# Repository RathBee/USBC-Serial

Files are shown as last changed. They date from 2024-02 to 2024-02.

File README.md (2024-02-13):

A compact USB-C to UART bridge with independent UART IO power rail utlizing the CH343 chip

Main features:

  1.UART interface I/O powered independently, never worry about backfeeding again.

  2.High baud rate. Maximum speed up to 6Mbps.

  3.Supports USB CDC driver. No annoying driver instalation anymore.

  4.Correctly implemented USB-C port, you can use any cable you like.
  (some badly designed USB-C device tends to lack the two 5.1k pull-down resistor, or shorts two cc pin together, causing the device to become unusable when using certain C to C cables)

  5.Compact. (2cm x 2.6cm)





Warning: Do not try to power you external circuit with this board's 3.3V pin, the CH343's internal regulator can only handle 10mA of current.
Instead, this pin should only be used to power the CH343's internal UART transciver. 

You can short the 5V pin to the VIO pin to get 5V level UART output. It's the same for 3.3V.

You can also power the CH343's UART transciver using your own power supply, for example, your MCU's power supply(assuming you are connecting this board to a MCU).
This way, you can have arbitary UART voltage level ranging from 1.7V to 5.5V. And you don't have to worry about backfeeding.

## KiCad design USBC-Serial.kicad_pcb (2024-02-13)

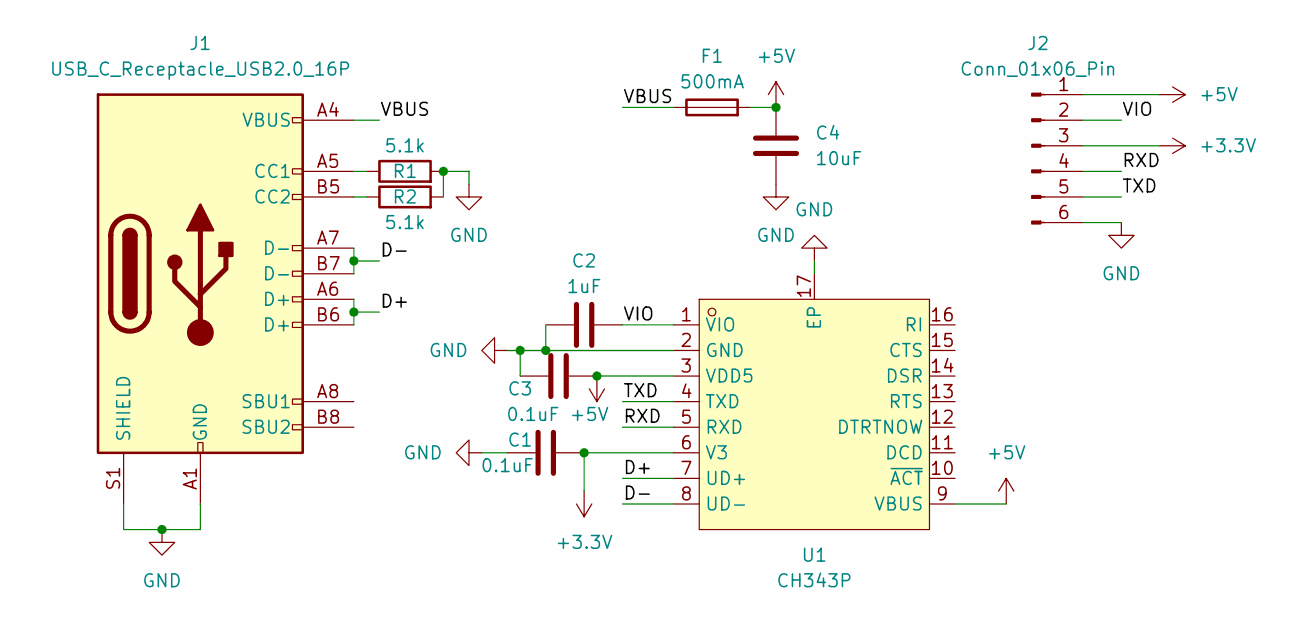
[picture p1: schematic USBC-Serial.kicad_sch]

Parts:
C1, C3: 0.1uF; C_0805_2012Metric
C2: 1uF; C_0805_2012Metric
C4: 10uF; C_0805_2012Metric
F1: 500mA; Fuse_1206_3216Metric
J1: USB_C_Receptacle_USB2.0_16P; USB_C_Receptacle_HRO_TYPE-C-31-M-12
J2: Conn_01x06_Pin; PinHeader_1x06_P2.54mm_Horizontal
R1, R2: 5.1k; R_0805_2012Metric
U1: CH343P; TQFN-16_L3.0-W3.0-P0.50-BL-EP1.7; LCSC Part C2846043

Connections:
+3.3V: C1.1, J2.3, U1.6 (V3)
+5V: C3.2, C4.1, F1.2, J2.1, U1.3 (VDD5), U1.9 (VBUS)
/D+: J1.A6 (D+), J1.B6 (D+), U1.7 (UD+)
/D-: J1.A7 (D-), J1.B7 (D-), U1.8 (UD-)
/RXD: J2.4, U1.5 (RXD)
/TXD: J2.5, U1.4 (TXD)
/VBUS: F1.1, J1.A4 (VBUS), J1.A9 (VBUS), J1.B4 (VBUS), J1.B9 (VBUS)
/VIO: C2.2, J2.2, U1.1 (VIO)
GND: C1.2, C2.1, C3.1, C4.2, J1.A1 (GND), J1.A12 (GND), J1.B1 (GND), J1.B12 (GND), J1.S1 (SHIELD), J2.6, R1.2, R2.2, U1.2 (GND), U1.17 (EP)
unnamed: J1.A5 (CC1), R1.1
unnamed: J1.B5 (CC2), R2.1

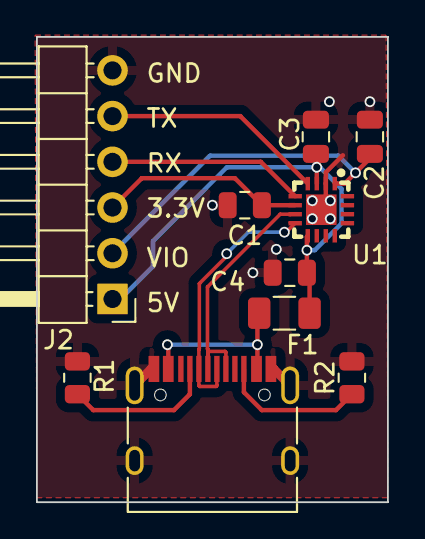
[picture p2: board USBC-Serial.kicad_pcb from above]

Board: 2 copper layers, 19.5 x 25.9 mm, 10 parts (0 on the bottom side), 11 nets.

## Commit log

2024-02-07 Add license file
    [USBC-Serial.kicad_pcb]
2024-02-07 add Type-C GND to shell connection
    [USBC-Serial.kicad_pcb]
2024-02-07 remove offensive text
    [USBC-Serial.kicad_sch]
2024-02-07 add schematic image to README
2024-02-08 Redo D+ D- track, reroute R1 R2
    [USBC-Serial.kicad_pcb]
2024-02-08 nuke everything - major refactor
    [USBC-Serial.kicad_pcb]
2024-02-08 refactor, rotated the main chip for 90 degrees
    [USBC-Serial.kicad_pcb]
2024-02-08 move J2 to the left, conserve some more space
    [USBC-Serial.kicad_pcb]
2024-02-08 add text, delete old gerber files
    [USBC-Serial.kicad_pcb]
2024-02-08 raret R1 and R2
    [USBC-Serial.kicad_pcb]
2024-02-13 fix bypass caps' ground return path
    [USBC-Serial.kicad_pcb]
2024-02-13 fix bypass caps
    [USBC-Serial.kicad_pcb]
